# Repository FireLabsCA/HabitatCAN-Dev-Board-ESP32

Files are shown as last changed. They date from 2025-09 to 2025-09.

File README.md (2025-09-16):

# HabitatCAN Dev Board (ESP32)

A development board designed for HabitatCAN home automation applications, featuring an ESP32-C3-MINI-1 microcontroller with integrated CAN bus transceiver and comprehensive I/O capabilities.

## Overview

The HabitatCAN Dev Board is a development platform for building HabitatCAN-compatible devices. HabitatCAN is an open standard for home automation built on the Controller Area Network (CAN) bus, providing reliable, low-latency communication between sensors, switches, actuators, and controllers in residential and light commercial environments.

Unlike proprietary systems (Control4, KNX, Zigbee), HabitatCAN is designed to be open, inexpensive, and implementable on common microcontrollers. It leverages structured cabling (Ethernet Cat5e/Cat6) for wiring but uses CAN signaling rather than Ethernet, allowing for robust operation in electrically noisy environments and over long distances.

## What is HabitatCAN?

HabitatCAN is a local-first home automation standard that provides:

- **Reliable Communication**: CAN bus ensures robust, real-time communication over structured cabling
- **Local-First Design**: Homes continue to function without Internet or cloud connectivity
- **Fault Isolation**: Failures are isolated and recovered automatically
- **Simple Devices**: Minimal logic in devices, complexity handled by controllers
- **Extensibility**: New device types and commands can be added without breaking older firmware

### Key Features of HabitatCAN:
- **500 kbit/s CAN bus** over Cat5e/Cat6 cabling (~100m reach)
- **24V courtesy power** distributed over structured cabling
- **Hierarchical addressing**: NetworkID (16-bit) + RoomID (8-bit) + NodeID (8-bit)
- **Automatic device discovery** and commissioning
- **Group and scene support** for complex automation
- **Fault tolerance** with backup controllers and local autonomy

## Board Images

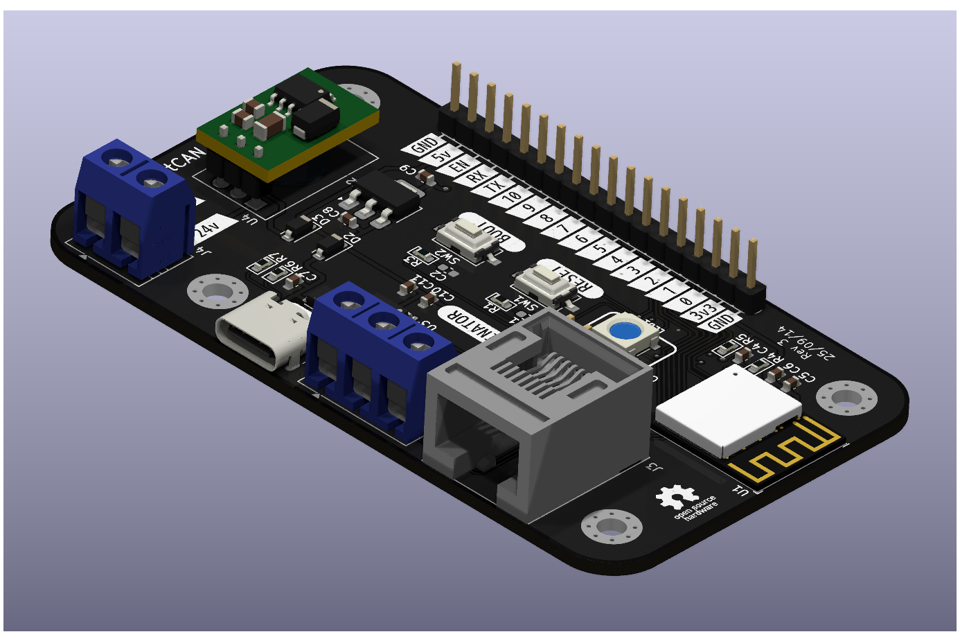
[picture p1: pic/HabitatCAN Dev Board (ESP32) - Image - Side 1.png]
HabitatCAN Dev Board - Side 1


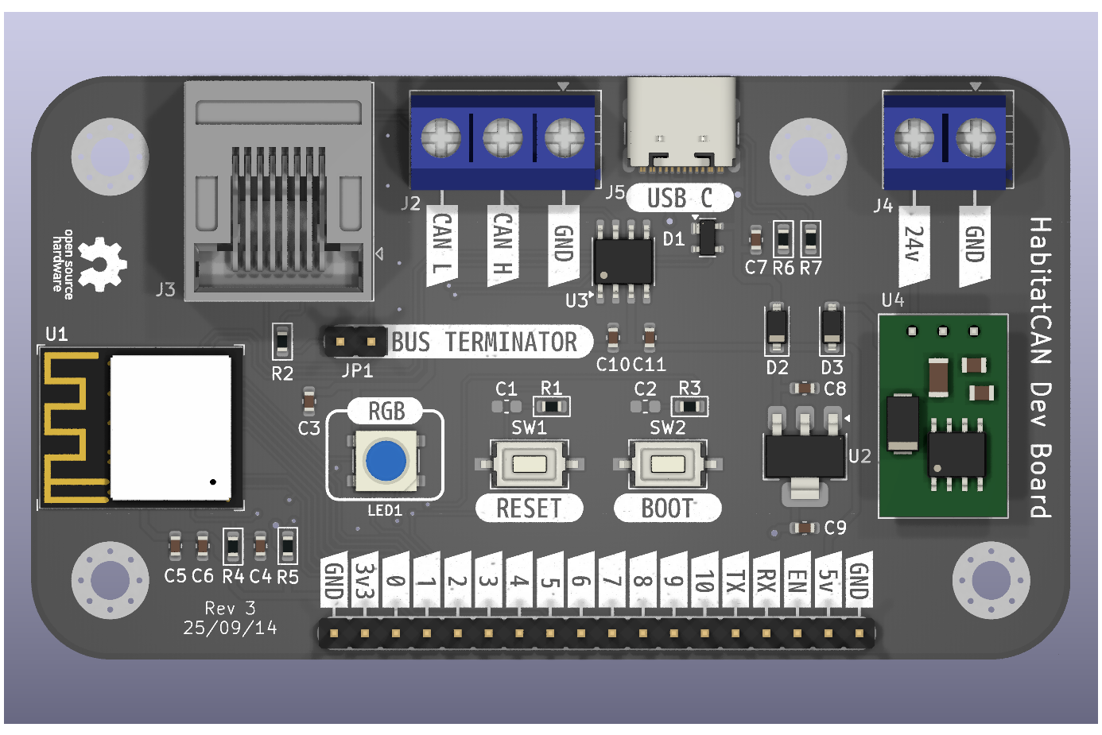
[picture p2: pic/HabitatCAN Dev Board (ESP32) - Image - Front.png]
HabitatCAN Dev Board - Front


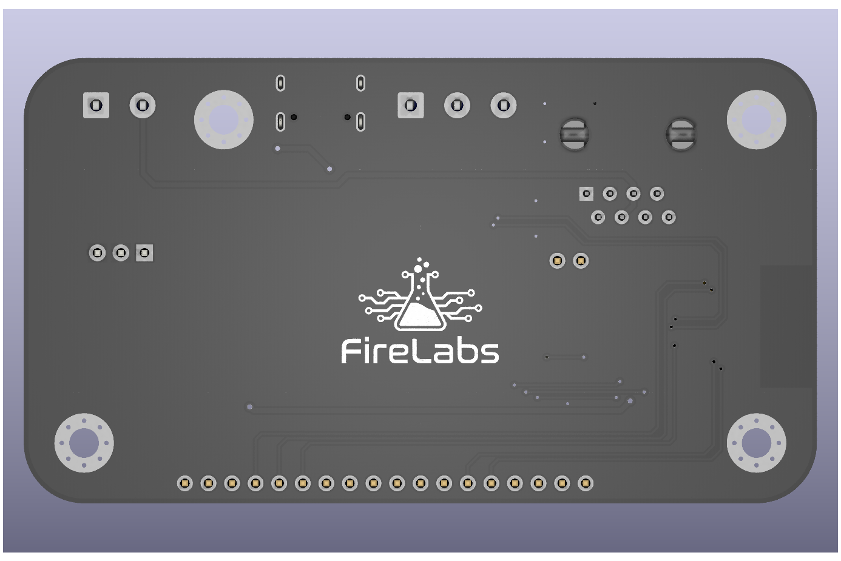
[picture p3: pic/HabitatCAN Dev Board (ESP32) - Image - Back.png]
HabitatCAN Dev Board - Back


## Key Features

### Microcontroller
- **ESP32-C3-MINI-1**: Ultra-low-power MCU with 2.4 GHz Wi-Fi and Bluetooth Low Energy
- **RISC-V 32-bit single-core processor**
- **400 KB SRAM, 384 KB ROM**
- **Built-in Wi-Fi and Bluetooth connectivity**

### CAN Bus Interface
- **TJA1051T CAN Transceiver**: High-speed CAN transceiver with silent mode
- **RJ45 Connector**: Standard Ethernet-style connector for HabitatCAN network connection
- **HabitatCAN Compliant**: Follows HabitatCAN specification for structured cabling

### Power Management
- **USB-C Power Input**: 5V input via USB-C connector
- **24V Input Support**: Optional 24V input with step-down conversion

### I/O Capabilities
- **18-pin GPIO Header**: All ESP32-C3 GPIO pins accessible
- **Serial Communication**: UART0 (TX/RX) pins available
- **ADC Channels**: Multiple analog input channels
- **Boot/Reset Controls**: Dedicated boot and reset buttons
- **Status LED**: Built-in status indicator
- **USB-C Programming**: Direct programming via USB-C

## Pinout

### GPIO Header (J1)
| Pin | Function | Description |
|-----|---|---|
| 1 | GND | Ground |
| 2 | 3V3 | 3.3V Power  |
| 3 | GPIO0 | GPIO0 / Boot |
| 4 | GPIO1 | GPIO1 |
| 5 | GPIO2 | GPIO2 |
| 6 | GPIO3 | GPIO3 |
| 7 | GPIO4 | GPIO4 / CAN RX |
| 8 | GPIO5 | GPIO5 / CAN TX |
| 9 | GPIO6 | GPIO6 |
| 10  | GPIO7 | GPIO7 |
| 11  | GPIO8 | GPIO8 / Status LED |
| 12  | GPIO9 | GPIO9 |
| 13  | GPIO10 | GPIO10 |
| 14  | S_TX | Serial TX |
| 15  | S_RX | Serial RX |
| 16  | EN | Enable / Reset |
| 17  | 5V | 5V Power |
| 18  | GND | Ground |

### CAN Bus Connector (J3) - HabitatCAN Compliant
| Pin | Function | Description |
|-----|---|---|
| 1 | GND | Ground |
| 2 | GND | Ground |
| 3 | CAN_H | CAN High |
| 4 | +24V | 24V Courtesy Power |
| 5 | +24V | 24V Courtesy Power |
| 6 | CAN_L | CAN Low |
| 7 | Reserved | Reserved for future use |
| 8 | Reserved | Reserved for future use |

### I2C Connector (J6) - QWIIC Compliant
| Pin | Function | Description |
|-----|---|---|
| 1 | GND | Ground |
| 1 | 3V3 | 3.3V Power |
| 1 | SDA | Serial Data |
| 1 | SCL | Serial Clock |

## HabitatCAN Development

### Device Types
This development board can be used to create various HabitatCAN device types:

**Sensors:**
- Door/Window sensors
- Motion sensors  
- Temperature sensors
- CO₂ sensors
- Humidity sensors
- Light sensors

**Switches:**
- Light switches
- Scene switches
- Dimmer controls

**Actuators:**
- Relay/Outlet controllers
- Dimmer controllers
- Blind controllers
- RGB/CCT lighting controllers

### HabitatCAN Protocol
The board implements the HabitatCAN protocol with:
- **Device Discovery**: Automatic UID-based device identification
- **Address Assignment**: RoomID/NodeID assignment by Room Controllers
- **Message Types**: FAULT, DISCOVER, ASSIGN, HEARTBEAT, COMMAND, GROUP, TELEMETRY
- **Security**: HMAC authentication for critical frames
- **Group/Scene Support**: Integration with HabitatCAN automation

## Getting Started

### Prerequisites
- Arduino IDE with ESP32 board support, or
- PlatformIO, or
- ESP-IDF development framework
- USB-C cable for programming and power
- HabitatCAN network infrastructure (Room Controller, Main Controller)

### Programming
1. Connect the board to your computer via USB-C
2. Install the ESP32 board package in your development environment
3. Select the ESP32-C3 board variant
4. Upload your HabitatCAN-compatible firmware

### HabitatCAN Network Setup
1. Connect the RJ45 connector to your HabitatCAN network
2. Ensure proper termination (automatic if used as end device)
3. The device will automatically discover and request address assignment
4. Configure device type and capabilities in your firmware

## Hardware Design

### Schematic
The board design is available in KiCad format in the `cad/` directory:
- Main schematic: `HabitatCAN Dev Board (ESP32).kicad_sch`
- PCB layout: `HabitatCAN Dev Board (ESP32).kicad_pcb`

### Manufacturing Files
Gerber files for PCB manufacturing are available in the `cad/Gerber/` directory:
- Copper layers (F_Cu, B_Cu)
- Solder mask (F_Mask, B_Mask)
- Silkscreen (F_Silkscreen, B_Silkscreen)
- Solder paste (F_Paste, B_Paste)
- Drill files (PTH.drl, NPTH.drl)

### Panel Design
A panelized version is available for batch manufacturing in the `cad/Panel/` directory.

## Revision History

- **Rev 4 (2025-09-15)**: Added QWIIC interface
- **Rev 3 (2025-09-14)**: Cleaned up bugs and silkscreen layer (archived in `cad/Rev3/`)
- **Rev 2**: Previous revision (archived in `cad/Rev2/`)
- **Rev 1**: Initial design

## License

This project is licensed under the Creative Commons Attribution-ShareAlike 4.0 International License. See `LICENSE.md` for details.

## Contributing

Contributions are welcome! Please feel free to submit issues, feature requests, or pull requests.

## Support

For questions and support, please open an issue in this repository.

---

*This development board is designed for HabitatCAN home automation development. Always follow proper safety guidelines when working with electrical circuits and home automation systems.*

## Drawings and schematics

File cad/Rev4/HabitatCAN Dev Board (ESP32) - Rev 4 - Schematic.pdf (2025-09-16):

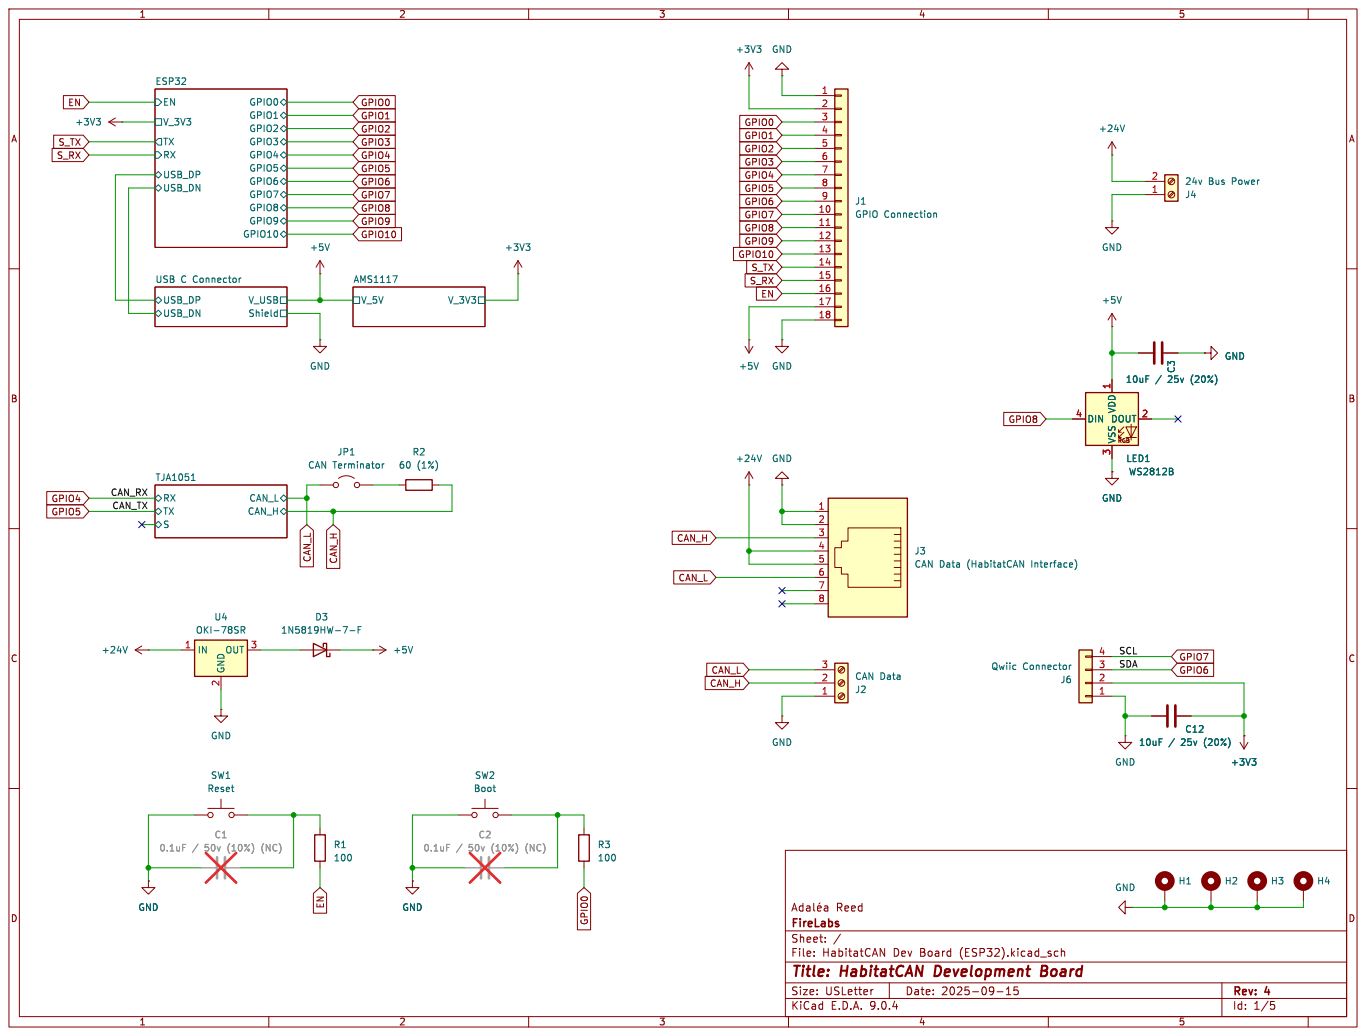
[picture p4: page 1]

Id: 1/5 Title: HabitatCAN Development Board

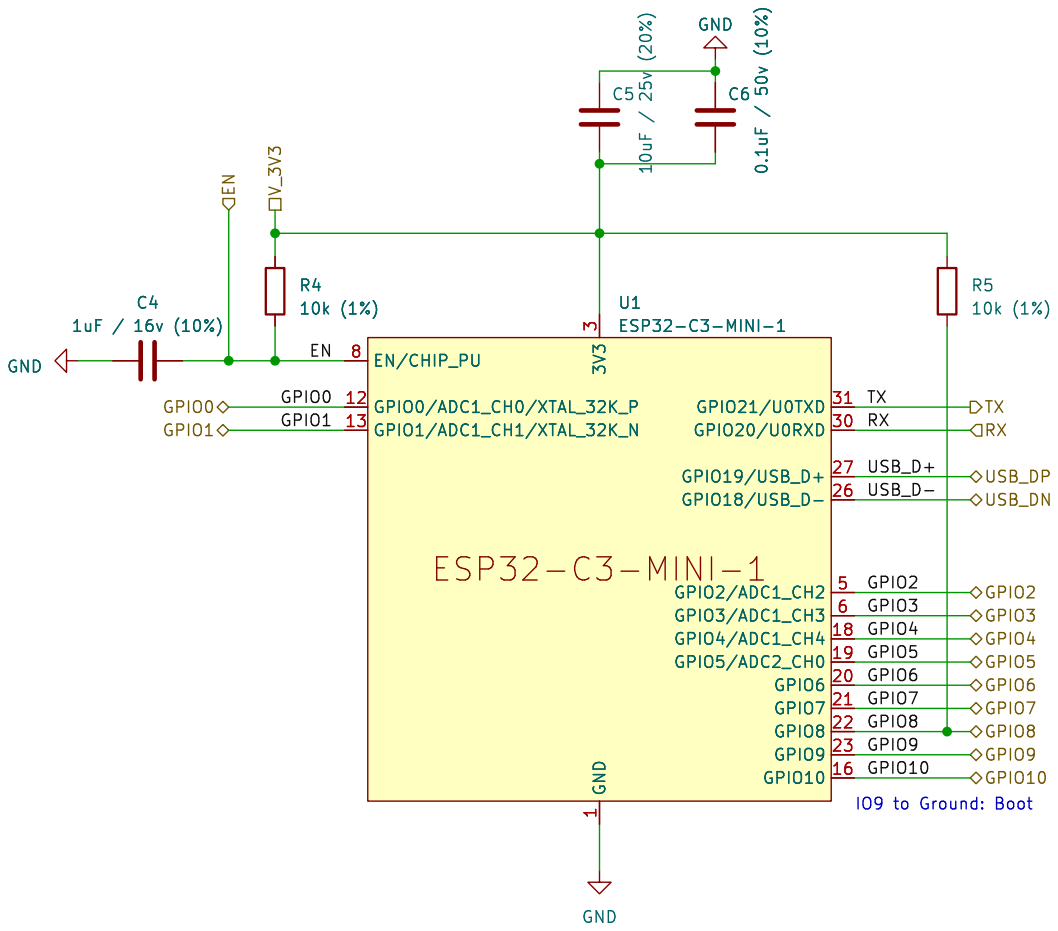
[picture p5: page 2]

Id: 2/5 Title: ESP32 C3 Mini 1 Microprocessor File: ic_esp32_c3_mini.kicad_sch Sheet: /ESP32/ FireLabs

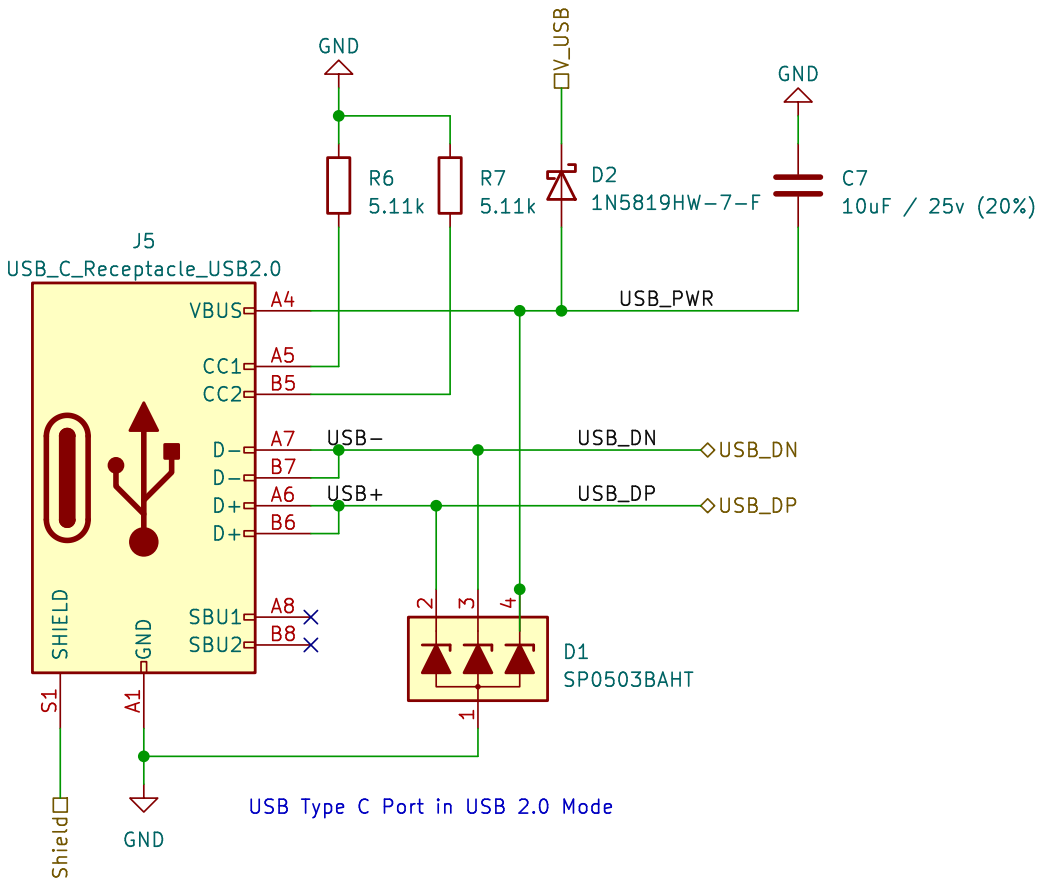
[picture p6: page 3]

USB_DP USB Type C Port in USB 2.0 Mode

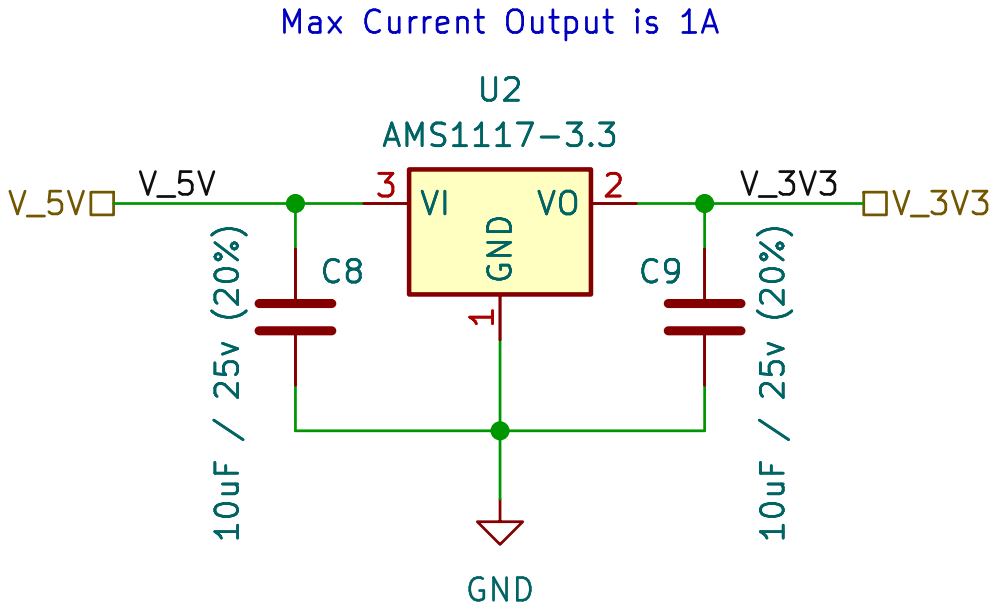
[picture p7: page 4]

þÿAdaléa Reed
Id: 4/5 Title: 5v to 3v3 Regulator File: ic_ams1117-3.3.kicad_sch Sheet: /AMS1117/ FireLabs

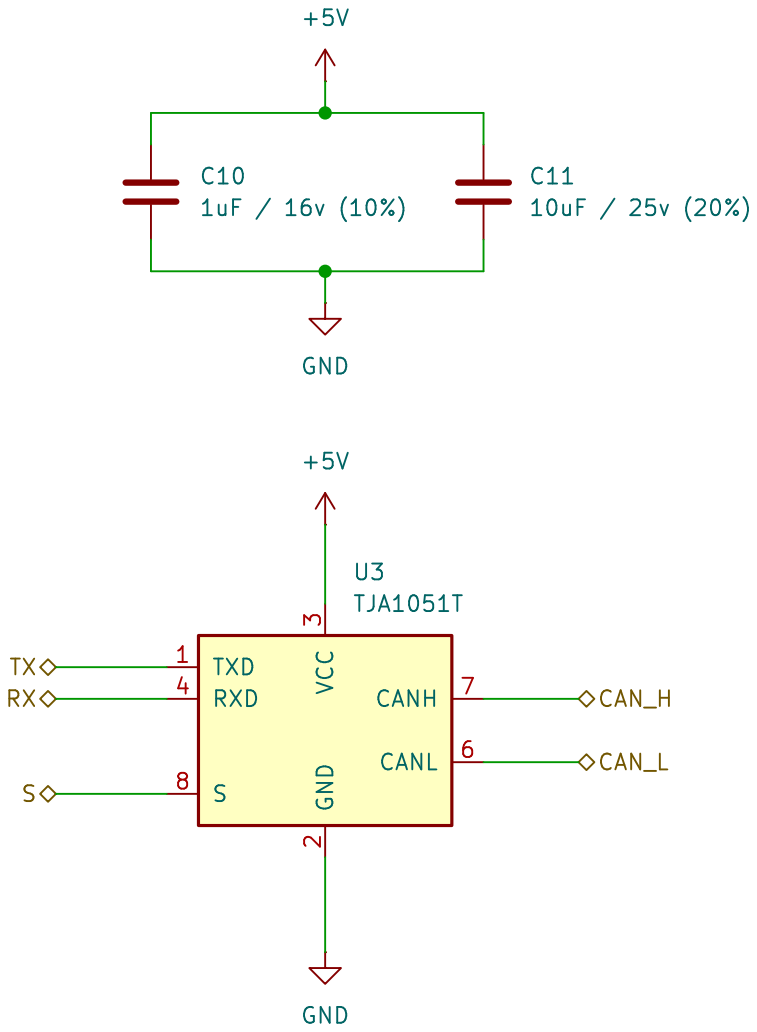
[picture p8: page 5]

þÿAdaléa Reed
Id: 5/5 Title: TJA1051T Can Bus Tranciever File: ic_tja1051.kicad_sch Sheet: /TJA1051/ FireLabs

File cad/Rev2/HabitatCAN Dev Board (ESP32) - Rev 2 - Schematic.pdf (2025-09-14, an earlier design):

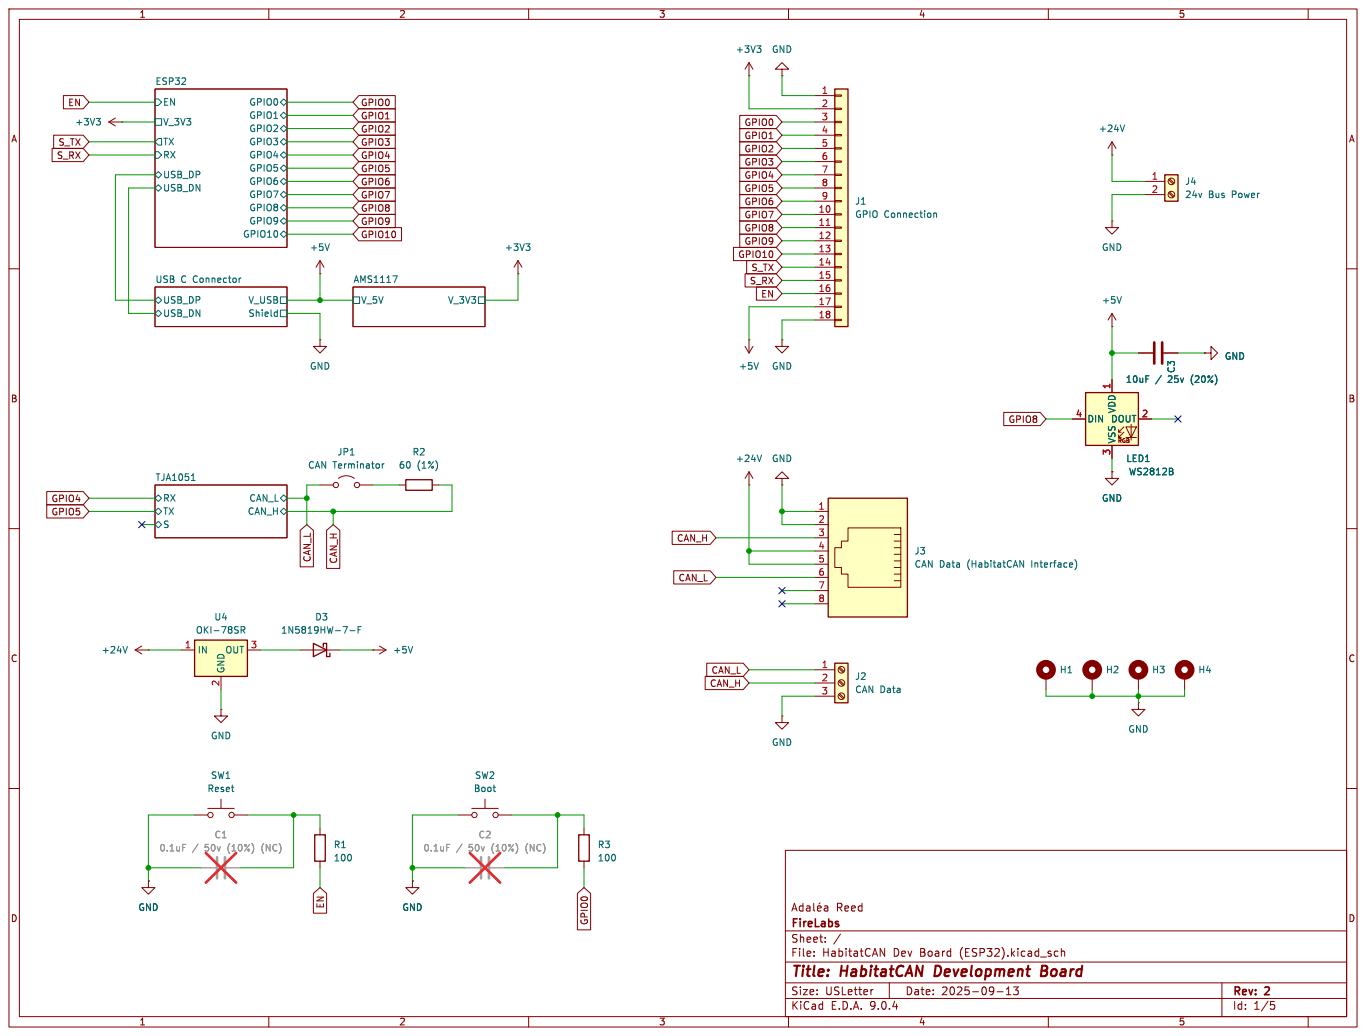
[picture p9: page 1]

Id: 1/5 Title: HabitatCAN Development Board


Id: 2/5 Title: ESP32 C3 Mini 1 Microprocessor File: ic_esp32_c3_mini.kicad_sch Sheet: /ESP32/ FireLabs

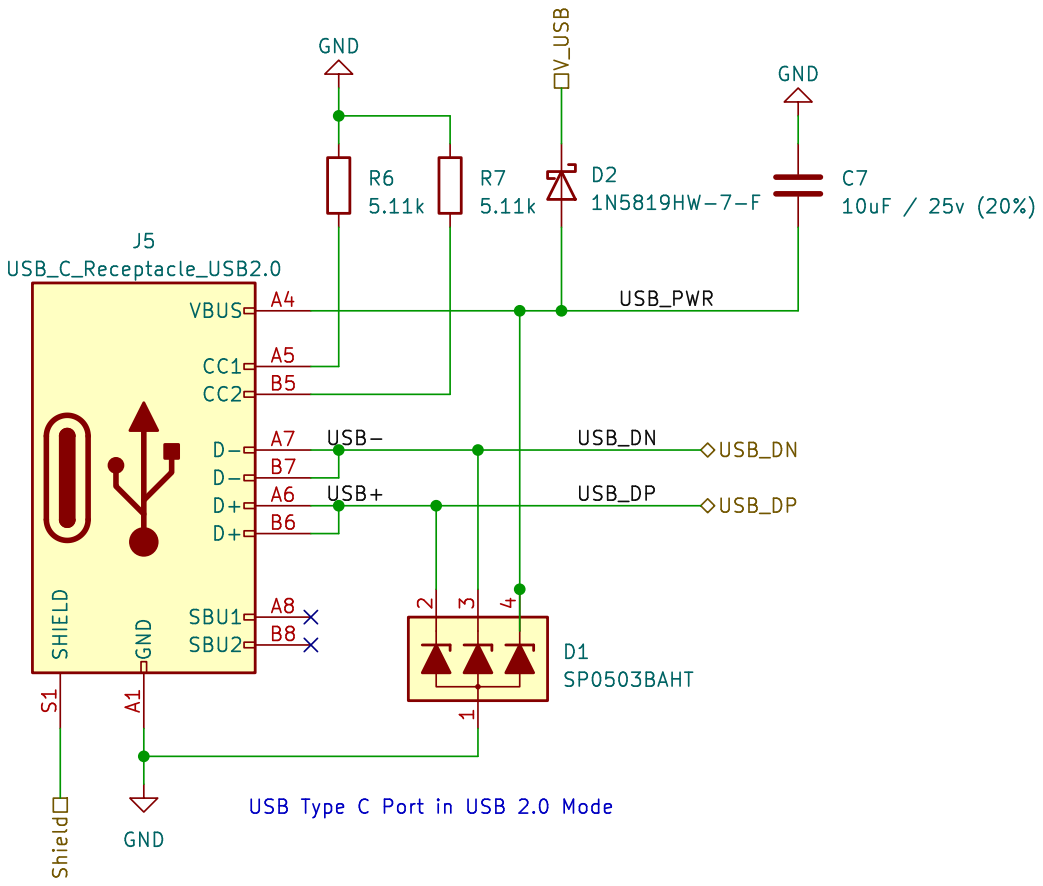
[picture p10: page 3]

USB_DP USB Type C Port in USB 2.0 Mode


þÿAdaléa Reed
Id: 4/5 Title: 5v to 3v3 Regulator File: ic_ams1117-3.3.kicad_sch Sheet: /AMS1117/ FireLabs


þÿAdaléa Reed
Id: 5/5 Title: TJA1051T Can Bus Tranciever File: ic_tja1051.kicad_sch Sheet: /TJA1051/ FireLabs

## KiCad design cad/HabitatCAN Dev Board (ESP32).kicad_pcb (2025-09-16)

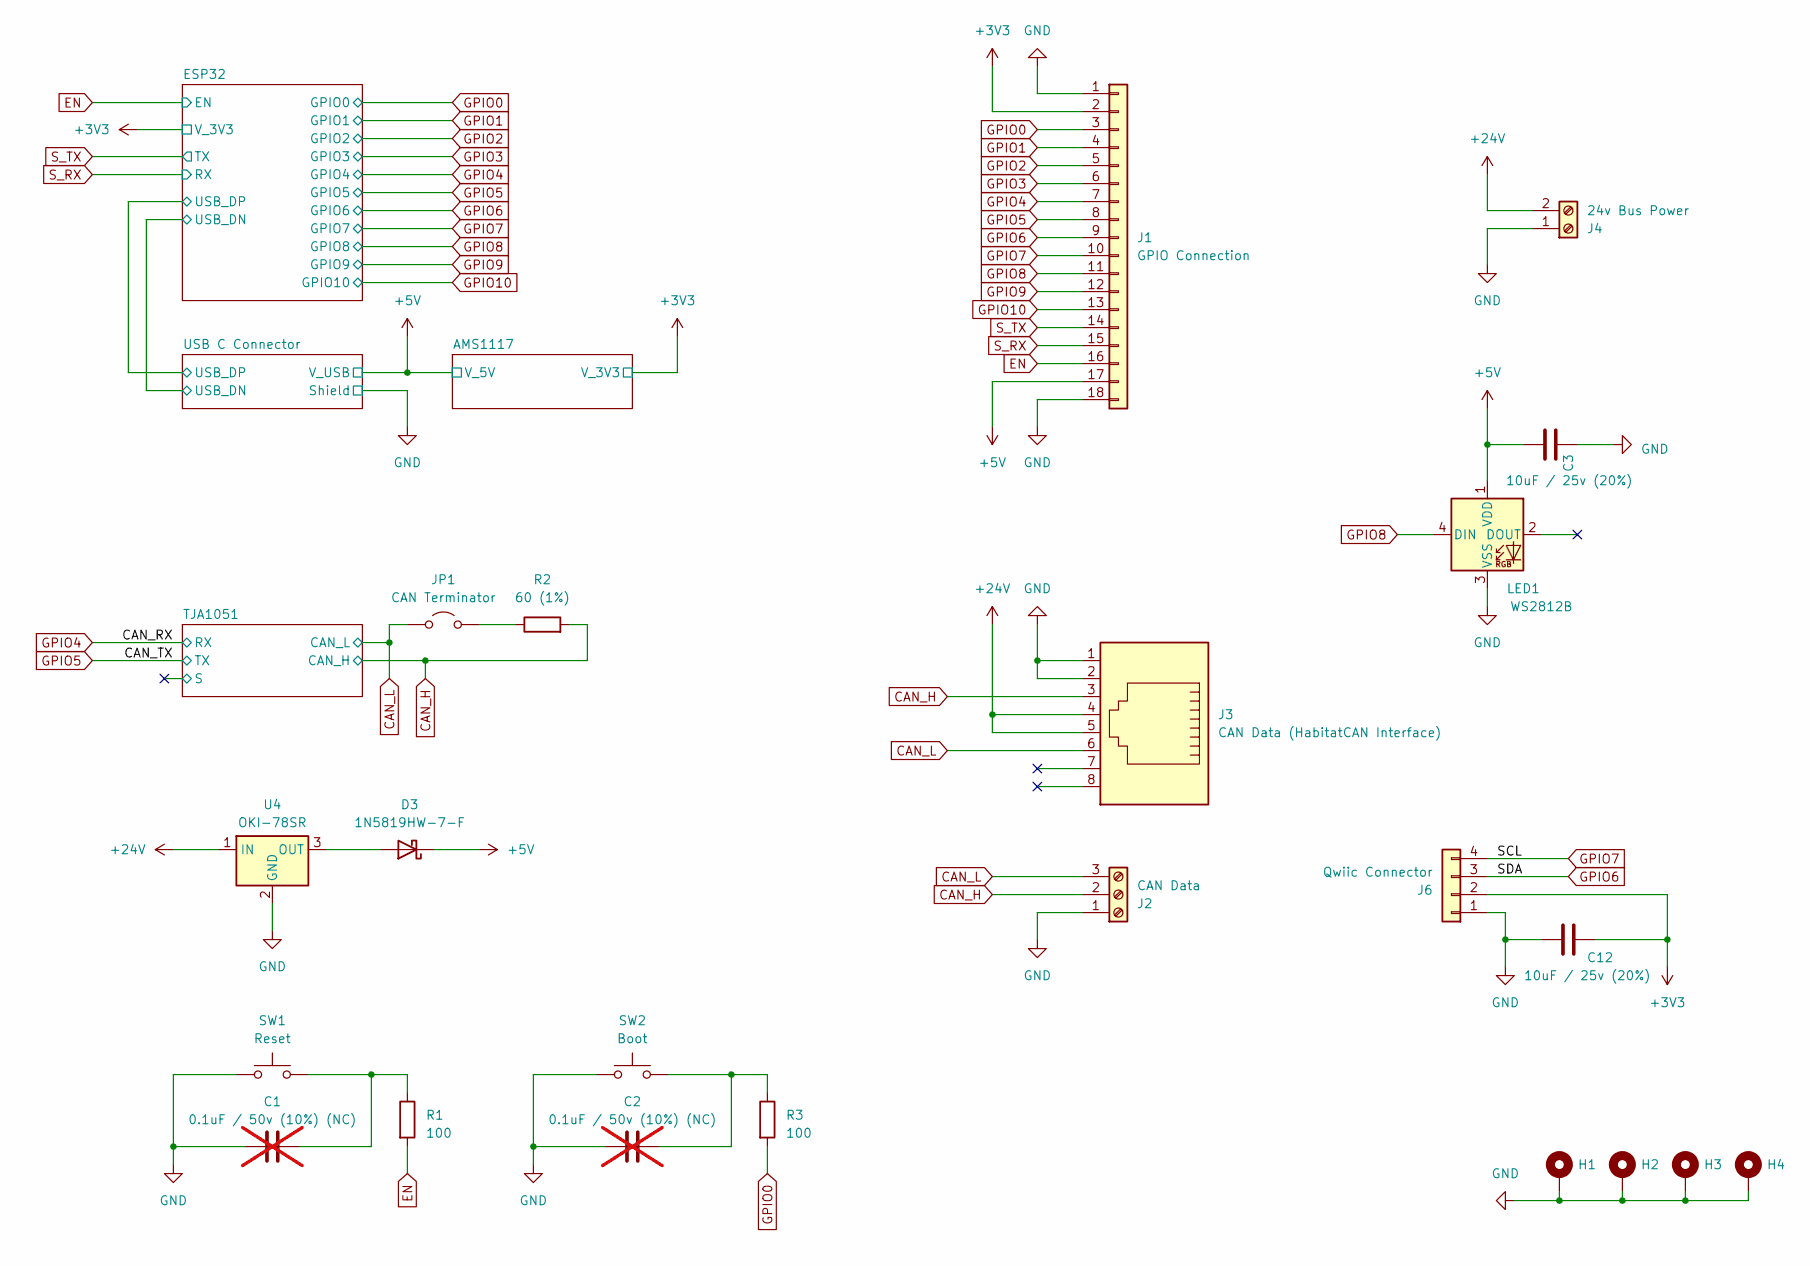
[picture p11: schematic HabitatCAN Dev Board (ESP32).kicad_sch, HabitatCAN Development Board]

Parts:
C1, C2: 0.1uF / 50v (10%) (NC); C_0603_1608Metric; not fitted
C3, C12: 10uF / 25v (20%); C_0603_1608Metric
D3: 1N5819HW-7-F; D_SOD-123; DigiKey 1N5819HW-FDICT-ND
H1, H2, H3, H4: MountingHole_Pad; MountingHole_3.2mm_M3_Pad_Via
J1: GPIO Connection; PinHeader_1x18_P2.54mm_Vertical
J2: CAN Data; TerminalBlock_MaiXu_MX126-5.0-03P_1x03_P5.00mm
J3: CAN Data (HabitatCAN Interface); RJ45_Amphenol_54602-x08_Horizontal
J4: 24v Bus Power; TerminalBlock_MaiXu_MX126-5.0-02P_1x02_P5.00mm
J6: Qwiic Connector; JST_SH_BM04B-SRSS-TB_1x04-1MP_P1.00mm_Vertical
JP1: CAN Terminator; PinHeader_1x02_P2.54mm_Vertical
LED1: WS2812B; LED_WS2812B_PLCC4_5.0x5.0mm_P3.2mm
R1, R3: 100; R_0603_1608Metric; DigiKey RMCF0603JT5K10CT-ND
R2: 60 (1%); R_0603_1608Metric
SW1: Reset; SW_Tactile_SPST_NO_Straight_CK_PTS636Sx25SMTRLFS
SW2: Boot; SW_Tactile_SPST_NO_Straight_CK_PTS636Sx25SMTRLFS
U4: OKI-78SR; Converter_DCDC_Murata_OKI-78SR_Horizontal

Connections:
+3V3: C12.2, J1.2, J6.2; also elsewhere on the board
+5V: C3.1, D3.1 (K), J1.17, LED1.1 (VDD); also elsewhere on the board
+24V: J3.4, J3.5, J4.2, U4.1 (IN)
CAN_H: J2.2, J3.3, R2.2; also elsewhere on the board
CAN_L: J2.3, J3.6, JP1.1 (A); also elsewhere on the board
EN: J1.16, R1.2; also elsewhere on the board
GND: C1.1, C2.1, C3.2, C12.1, H1.1, H2.1, H3.1, H4.1, J1.1, J1.18, J2.1, J3.1, J3.2, J4.1, J6.1, LED1.3 (VSS), SW1.1, SW2.1, U4.2 (GND); also elsewhere on the board
GPIO0: J1.3, R3.2; also elsewhere on the board
GPIO1: J1.4; also elsewhere on the board
GPIO2: J1.5; also elsewhere on the board
GPIO3: J1.6; also elsewhere on the board
GPIO4: J1.7; also elsewhere on the board
GPIO5: J1.8; also elsewhere on the board
GPIO6: J1.9, J6.3; also elsewhere on the board
GPIO7: J1.10, J6.4; also elsewhere on the board
GPIO8: J1.11, LED1.4 (DIN); also elsewhere on the board
GPIO9: J1.12; also elsewhere on the board
GPIO10: J1.13; also elsewhere on the board
unnamed: C1.2, R1.1, SW1.2
unnamed: C2.2, R3.1, SW2.2
unnamed: D3.2 (A), U4.3 (OUT)
unnamed: JP1.2 (B), R2.1
S_RX: J1.15; also elsewhere on the board
S_TX: J1.14; also elsewhere on the board

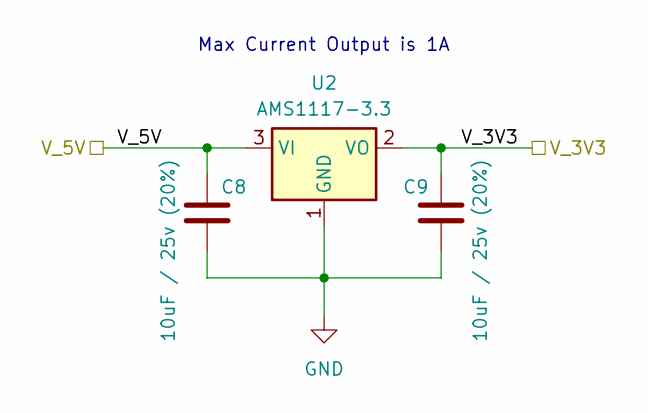
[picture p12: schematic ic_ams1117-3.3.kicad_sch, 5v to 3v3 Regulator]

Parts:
C8, C9: 10uF / 25v (20%); C_0603_1608Metric; DigiKey 1276-1869-1-ND
U2: AMS1117-3.3; SOT-223-3_TabPin2; DigiKey 4518-AMS1117CD-3.3CT-ND

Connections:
+3V3: C9.1, U2.2 (VO); also elsewhere on the board
+5V: C8.1, U2.3 (VI); also elsewhere on the board
GND: C8.2, C9.2, U2.1 (GND); also elsewhere on the board

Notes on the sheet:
Max Current Output is 1A

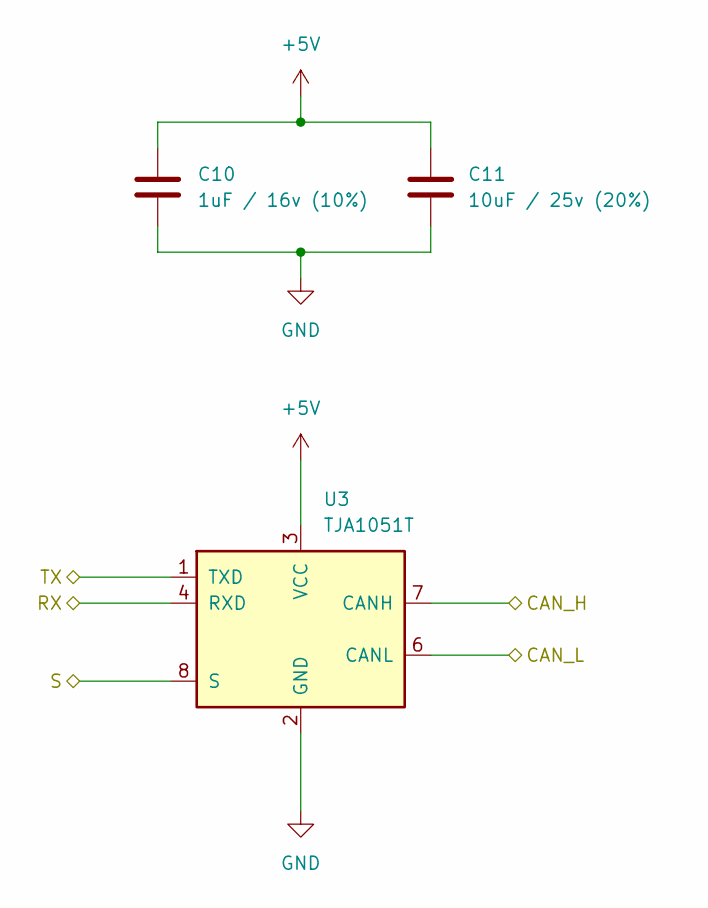
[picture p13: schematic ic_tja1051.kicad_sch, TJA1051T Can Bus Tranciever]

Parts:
C10: 1uF / 16v (10%); C_0603_1608Metric
C11: 10uF / 25v (20%); C_0603_1608Metric; DigiKey 1276-1869-1-ND
U3: TJA1051T; SOIC-8_3.9x4.9mm_P1.27mm

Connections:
+5V: C10.1, C11.1, U3.3 (VCC); also elsewhere on the board
/TJA1051/S: U3.8 (S)
CAN_H: U3.7 (CANH); also elsewhere on the board
CAN_L: U3.6 (CANL); also elsewhere on the board
GND: C10.2, C11.2, U3.2 (GND); also elsewhere on the board
GPIO4: U3.4 (RXD); also elsewhere on the board
GPIO5: U3.1 (TXD); also elsewhere on the board

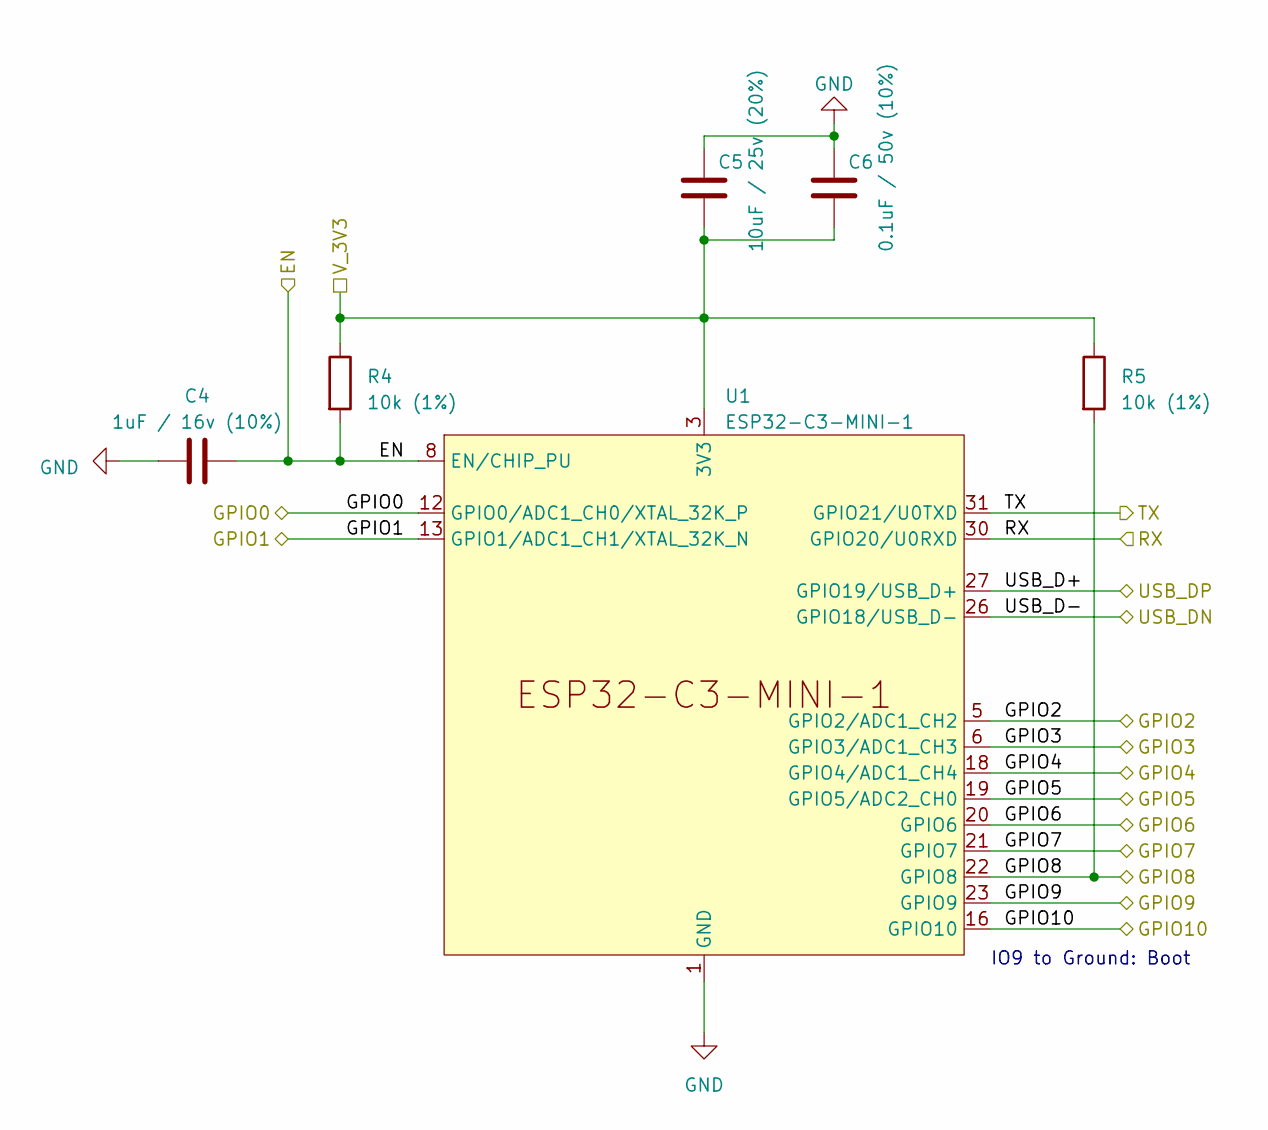
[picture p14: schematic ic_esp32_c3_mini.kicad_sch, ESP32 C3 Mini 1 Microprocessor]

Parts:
C4: 1uF / 16v (10%); C_0603_1608Metric
C5: 10uF / 25v (20%); C_0603_1608Metric
C6: 0.1uF / 50v (10%); C_0603_1608Metric
R4, R5: 10k (1%); R_0603_1608Metric
U1: ESP32-C3-MINI-1

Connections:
+3V3: C5.1, C6.1, R4.1, R5.1, U1.3 (3V3); also elsewhere on the board
/ESP32/USB_D+: U1.27 (GPIO19/USB_D+); also elsewhere on the board
/ESP32/USB_D-: U1.26 (GPIO18/USB_D-); also elsewhere on the board
EN: C4.2, R4.2, U1.8 (EN/CHIP_PU); also elsewhere on the board
GND: C4.1, C5.2, C6.2, U1.1 (GND), U1.2 (GND), U1.11 (GND), U1.14 (GND), U1.36 (GND), U1.37 (GND), U1.38 (GND), U1.39 (GND), U1.40 (GND), U1.41 (GND), U1.42 (GND), U1.43 (GND), U1.44 (GND), U1.45 (GND), U1.46 (GND), U1.47 (GND), U1.48 (GND), U1.49 (GND), U1.50 (GND), U1.51 (GND), U1.52 (GND), U1.53 (GND); also elsewhere on the board
GPIO0: U1.12 (GPIO0/ADC1_CH0/XTAL_32K_P); also elsewhere on the board
GPIO1: U1.13 (GPIO1/ADC1_CH1/XTAL_32K_N); also elsewhere on the board
GPIO2: U1.5 (GPIO2/ADC1_CH2); also elsewhere on the board
GPIO3: U1.6 (GPIO3/ADC1_CH3); also elsewhere on the board
GPIO4: U1.18 (GPIO4/ADC1_CH4); also elsewhere on the board
GPIO5: U1.19 (GPIO5/ADC2_CH0); also elsewhere on the board
GPIO6: U1.20 (GPIO6); also elsewhere on the board
GPIO7: U1.21 (GPIO7); also elsewhere on the board
GPIO8: R5.2, U1.22 (GPIO8); also elsewhere on the board
GPIO9: U1.23 (GPIO9); also elsewhere on the board
GPIO10: U1.16 (GPIO10); also elsewhere on the board
S_RX: U1.30 (GPIO20/U0RXD); also elsewhere on the board
S_TX: U1.31 (GPIO21/U0TXD); also elsewhere on the board

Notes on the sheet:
IO9 to Ground: Boot

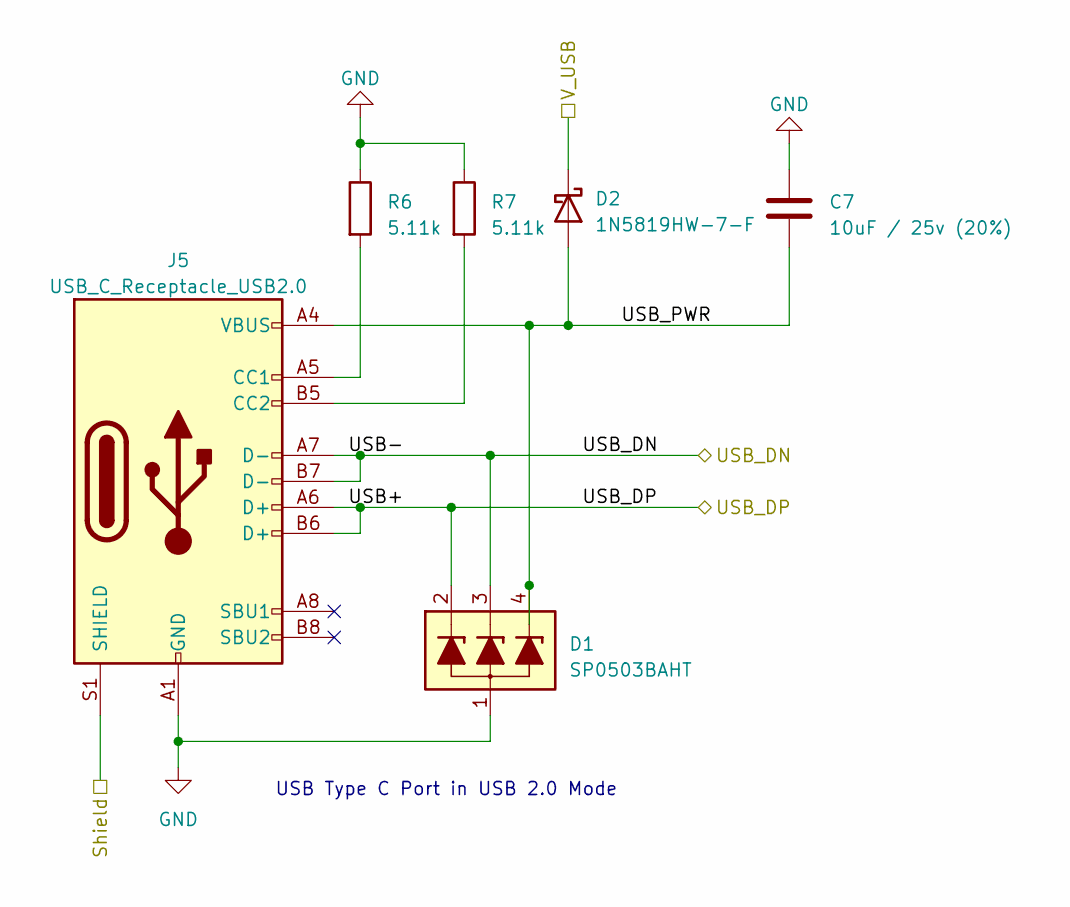
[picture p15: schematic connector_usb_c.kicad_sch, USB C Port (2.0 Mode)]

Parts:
C7: 10uF / 25v (20%); C_0603_1608Metric; DigiKey 1276-1869-1-ND
D1: SP0503BAHT; SOT-143
D2: 1N5819HW-7-F; D_SOD-123; DigiKey 1N5819HW-FDICT-ND
J5: USB_C_Receptacle_USB2.0; USB_C_Receptacle_GCT_USB4105-xx-A_16P_TopMnt_Horizontal; DigiKey 2073-USB4105-GF-ACT-ND
R6, R7: 5.11k; R_0603_1608Metric; DigiKey RMCF0603JT5K10CT-ND

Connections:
+5V: D2.1 (K); also elsewhere on the board
/ESP32/USB_D+: D1.2 (L1), J5.A6 (D+), J5.B6 (D+); also elsewhere on the board
/ESP32/USB_D-: D1.3 (L2), J5.A7 (D-), J5.B7 (D-); also elsewhere on the board
/USB C Connector/USB_PWR: C7.1, D1.4 (L3), D2.2 (A), J5.A4 (VBUS), J5.A9 (VBUS), J5.B4 (VBUS), J5.B9 (VBUS)
GND: C7.2, D1.1 (VN), J5.A1 (GND), J5.A12 (GND), J5.B1 (GND), J5.B12 (GND), J5.S1 (SHIELD), R6.1, R7.1; also elsewhere on the board
unnamed: J5.A5 (CC1), R6.2
unnamed: J5.B5 (CC2), R7.2

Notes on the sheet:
USB Type C Port in USB 2.0 Mode

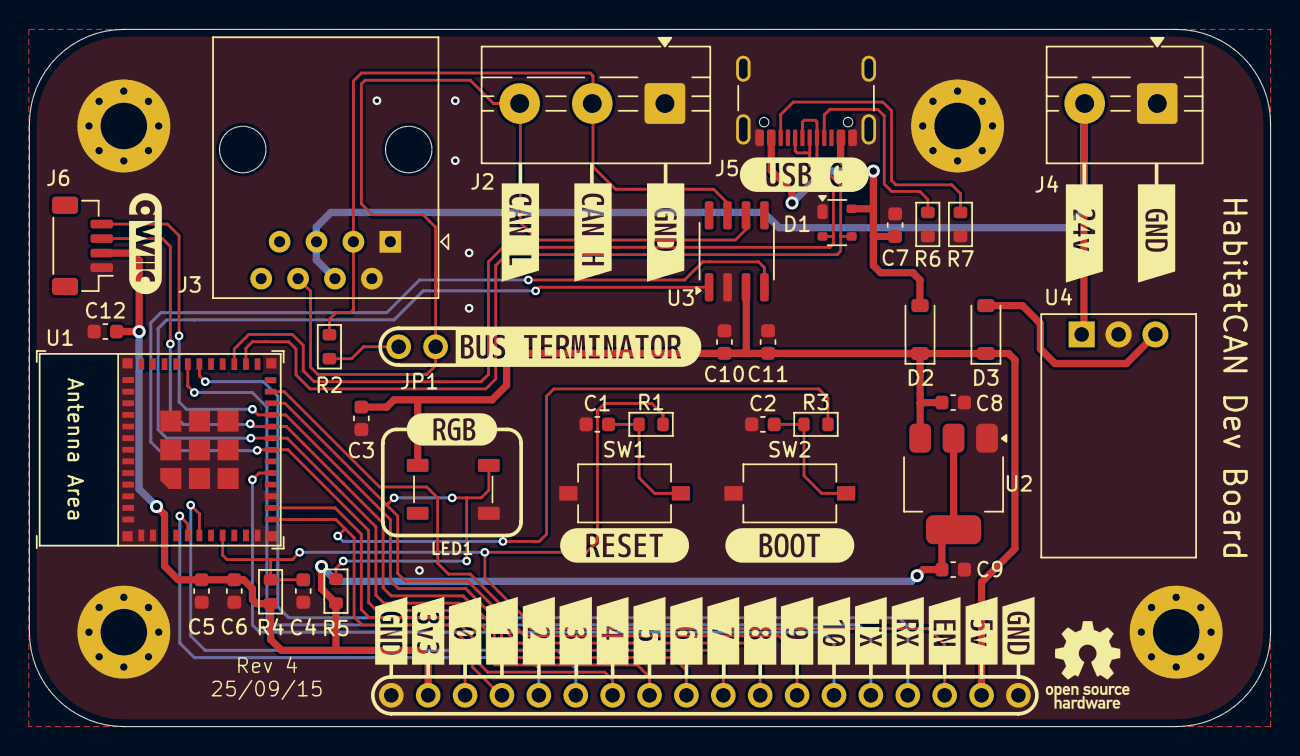
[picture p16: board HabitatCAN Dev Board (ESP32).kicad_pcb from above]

Board: 2 copper layers, 85.5 x 48.0 mm, 68 parts (0 on the bottom side), 29 nets.

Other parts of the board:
kibuzzard-68C5BCFF: G***; kibuzzard-68C5BCFF
kibuzzard-68C5BDE3: G***; kibuzzard-68C5BDE3
kibuzzard-68C5C7D3: G***; kibuzzard-68C5C7D3
kibuzzard-68C5C7EB: G***; kibuzzard-68C5C7EB
kibuzzard-68C5C8AB: G***; kibuzzard-68C5C8AB
kibuzzard-68C5C8C1: G***; kibuzzard-68C5C8C1
kibuzzard-68C5C8CC: G***; kibuzzard-68C5C8CC
kibuzzard-68C5C8DC: G***; kibuzzard-68C5C8DC
kibuzzard-68C5C8ED: G***; kibuzzard-68C5C8ED
kibuzzard-68C5C8FB: G***; kibuzzard-68C5C8FB
kibuzzard-68C5C81E: G***; kibuzzard-68C5C81E
kibuzzard-68C5C82A: G***; kibuzzard-68C5C82A
kibuzzard-68C5C84A: G***; kibuzzard-68C5C84A
kibuzzard-68C5C89F: G***; kibuzzard-68C5C89F
kibuzzard-68C5C90A: G***; kibuzzard-68C5C90A
kibuzzard-68C5C857: G***; kibuzzard-68C5C857
kibuzzard-68C5C878: G***; kibuzzard-68C5C878
kibuzzard-68C5C890: G***; kibuzzard-68C5C890
kibuzzard-68C5C916: G***; kibuzzard-68C5C916
kibuzzard-68C35A34: G***; kibuzzard-68C35A34
kibuzzard-68C35C66: G***; kibuzzard-68C35C66
kibuzzard-68C35D4D: G***; kibuzzard-68C35D4D
kibuzzard-68C35D6E: G***; kibuzzard-68C35D6E
kibuzzard-68C35D54, kibuzzard-68C35D54#2: G***; kibuzzard-68C35D54
kibuzzard-68C366C1: G***; kibuzzard-68C366C1
kibuzzard-68C366CA: G***; kibuzzard-68C366CA
kibuzzard-68C36393: G***; kibuzzard-68C36393

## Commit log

2025-09-14 initial upload
    [HabitatCAN Dev Board (ESP32) - Panel-B_Cu.gbr, HabitatCAN Dev Board (ESP32) - Panel-B_Mask.gbr, HabitatCAN Dev Board (ESP32) - Panel-B_Paste.gbr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]
2025-09-14 added rendered images of the board
2025-09-16 Updated to Rev4
    [HabitatCAN Dev Board (ESP32) - Panel-B_Cu.gbr, HabitatCAN Dev Board (ESP32) - Panel-B_Mask.gbr, HabitatCAN Dev Board (ESP32) - Panel-B_Paste.gbr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]
